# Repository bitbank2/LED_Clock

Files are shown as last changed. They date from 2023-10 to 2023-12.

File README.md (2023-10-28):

# LED_Clock
A CH32V003 low cost 'night clock'<br>
The PCB project was created with KiCad 7.0 and the firmware in the MounRiver Studio IDE. The target device is the TSSOP20 version of the CH32V003.
<br>
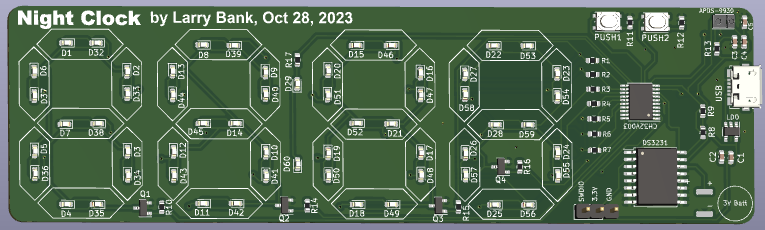
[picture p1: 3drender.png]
LED_Clock

<br>
<b>Why did you make it?</b><br>
We like to sleep in a completely black room with no LEDs visible. In the winter, the sun comes up later in the morning and it's useful to know what time it is if you wake up too early and can try to sleep a bit more. My idea was to create an LED clock which displays the time in the day and goes completely black at night. To display the time in a dark room, you wave your hand close to the clock and it will dimly display the time for a few seconds.<br>
<br>
The KiCad project files and gerbers (ready to produce at your favorite PCB fab) are in the PCB folder.<br>

If you find this project useful, please consider becoming a sponsor or sending a donation.



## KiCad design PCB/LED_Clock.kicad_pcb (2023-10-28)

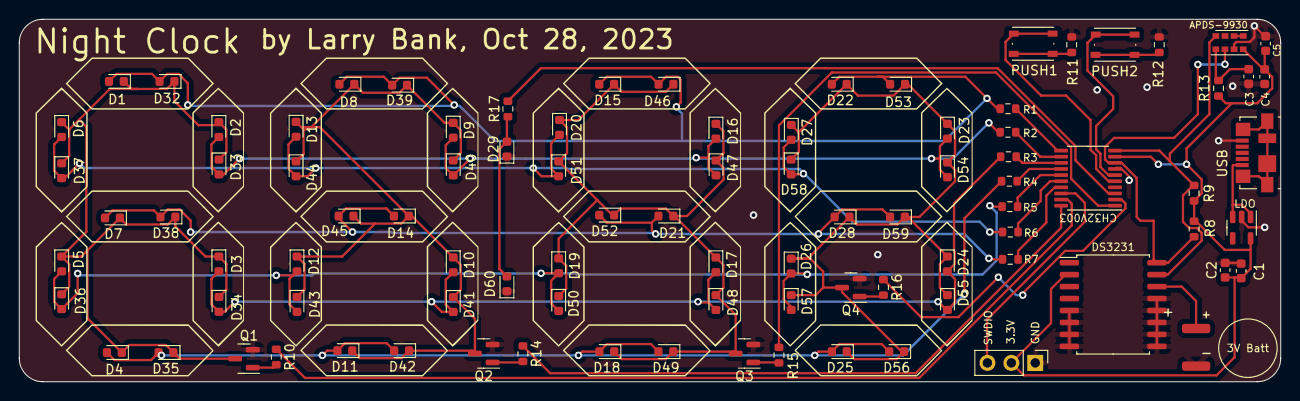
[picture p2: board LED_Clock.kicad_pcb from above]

Board: 2 copper layers, 134.0 x 38.5 mm, 93 parts (0 on the bottom side), 41 nets.

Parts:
3V Batt: Battery_Cell; CR44_Tabs
APDS-9930: APDS-9960; Avago_APDS-9960
C1, C5: 10uF; C_0603_1608Metric
C2: 100n; C_0603_1608Metric
C3, C4: 1uF; C_0603_1608Metric
CH32V003: CH32V003_TSSOP20; TSSOP-20_4.4x6.5mm_P0.65mm
D1, D2, D3, D4, D5, D6, D7, D8, D9, D10, D11, D12, D13, D14, D15, D16, D17, D18, D19, D20, D21, D22, D23, D24, D25, D26, D27, D28, D29, D32, D33, D34, D35, D36, D37, D38, D39, D40, D41, D42, D43, D44, D45, D46, D47, D48, D49, D50, D51, D52, D53, D54, D55, D56, D57, D58, D59, D60: LED; LED_0603_1608Metric
DS3231: DS3231M; SOIC-16W_7.5x10.3mm_P1.27mm
J3: PROG; PinHeader_1x03_P2.54mm_Vertical
LDO: AP2127K-3.3; SOT-23-5
PUSH1, PUSH2: SW_Push; SW_Push_1P1T_NO_Vertical_Wuerth_434133025816
Q1, Q2, Q3, Q4: AO3400A; SOT-23
R1, R2, R3, R4, R5, R6, R7, R17: 1K; R_0603_1608Metric
R8, R9: 4.7K; R_0603_1608Metric
R10, R14, R15, R16: 1k; R_0603_1608Metric
R11, R12: 10K; R_0603_1608Metric
R13: 22R; R_0603_1608Metric
USB: USB_B_Micro; USB_Micro-B_Molex_47346-0001

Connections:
+3.3V: APDS-9930.5 (LED_A), C1.1, C2.1, C4.1, C5.1, CH32V003.9 (VDD), DS3231.2 (VCC), J3.2, LDO.5 (VOUT), R8.2, R9.2, R13.2
BUTT0: CH32V003.5 (PA1/OSCI), PUSH1.2
BUTT1: CH32V003.6 (PA2/OSCO), PUSH2.2
COL1: CH32V003.19 (PD2), R10.1
COL2: CH32V003.20 (PD3), R14.1
COL3: CH32V003.1 (PD4), R15.1
COL4: CH32V003.2 (PD5), R16.1
COLON: CH32V003.3 (PD6), R17.2
GND: 3V Batt.2 (-), APDS-9930.6 (GND), C1.2, C2.2, C3.2, C4.2, C5.2, CH32V003.7 (VSS), D29.1 (K), D60.1 (K), DS3231.5 (GND), DS3231.6 (GND), DS3231.7 (GND), DS3231.8 (GND), DS3231.9 (GND), DS3231.10 (GND), DS3231.11 (GND), DS3231.12 (GND), DS3231.13 (GND), J3.1, LDO.2 (GND), Q1.2 (S), Q2.2 (S), Q3.2 (S), Q4.2 (S), R11.2, R12.2, USB.5 (GND)
unnamed: D1.2 (A), D8.2 (A), D15.2 (A), D22.2 (A), D32.2 (A), D39.2 (A), D46.2 (A), D53.2 (A), R1.1
unnamed: D1.1 (K), D2.1 (K), D3.1 (K), D4.1 (K), D5.1 (K), D6.1 (K), D7.1 (K), D32.1 (K), D33.1 (K), D34.1 (K), D35.1 (K), D36.1 (K), D37.1 (K), D38.1 (K), Q1.3 (D)
unnamed: D3.2 (A), D10.2 (A), D17.2 (A), D24.2 (A), D34.2 (A), D41.2 (A), D48.2 (A), D55.2 (A), R3.1
unnamed: D8.1 (K), D9.1 (K), D10.1 (K), D11.1 (K), D12.1 (K), D13.1 (K), D14.1 (K), D39.1 (K), D40.1 (K), D41.1 (K), D42.1 (K), D43.1 (K), D44.1 (K), D45.1 (K), Q2.3 (D)
unnamed: D4.2 (A), D11.2 (A), D18.2 (A), D25.2 (A), D35.2 (A), D42.2 (A), D49.2 (A), D56.2 (A), R4.1
unnamed: D5.2 (A), D12.2 (A), D19.2 (A), D26.2 (A), D36.2 (A), D43.2 (A), D50.2 (A), D57.2 (A), R5.1
unnamed: D6.2 (A), D13.2 (A), D20.2 (A), D27.2 (A), D37.2 (A), D44.2 (A), D51.2 (A), D58.2 (A), R6.1
unnamed: D7.2 (A), D14.2 (A), D21.2 (A), D28.2 (A), D38.2 (A), D45.2 (A), D52.2 (A), D59.2 (A), R7.1
unnamed: D15.1 (K), D16.1 (K), D17.1 (K), D18.1 (K), D19.1 (K), D20.1 (K), D21.1 (K), D46.1 (K), D47.1 (K), D48.1 (K), D49.1 (K), D50.1 (K), D51.1 (K), D52.1 (K), Q3.3 (D)
unnamed: D2.2 (A), D9.2 (A), D16.2 (A), D23.2 (A), D33.2 (A), D40.2 (A), D47.2 (A), D54.2 (A), R2.1
unnamed: D22.1 (K), D23.1 (K), D24.1 (K), D25.1 (K), D26.1 (K), D27.1 (K), D28.1 (K), D53.1 (K), D54.1 (K), D55.1 (K), D56.1 (K), D57.1 (K), D58.1 (K), D59.1 (K), Q4.3 (D)
unnamed: D29.2 (A), D60.2 (A), R17.1
unnamed: PUSH1.1, R11.1
unnamed: PUSH2.1, R12.1
unnamed: Q1.1 (G), R10.2
unnamed: Q2.1 (G), R14.2
unnamed: Q3.1 (G), R15.2
unnamed: Q4.1 (G), R16.2
unnamed: APDS-9930.3 (LDR), APDS-9930.4 (LED_K)
unnamed: APDS-9930.8 (VCC), C3.1, R13.1
ROW1: CH32V003.11 (PC1/SDA1), R1.2
ROW2: CH32V003.12 (PC2/SCL1), R2.2
ROW3: CH32V003.13 (PC3), R3.2
ROW4: CH32V003.14 (PC4), R4.2
ROW5: CH32V003.15 (PC5), R5.2
ROW6: CH32V003.16 (PC6), R6.2
ROW7: CH32V003.17 (PC7), R7.2
SCL: APDS-9930.7 (SCL), CH32V003.8 (PD0/SDA0), DS3231.16 (SCL), R8.1
SDA: APDS-9930.1 (SDA), CH32V003.10 (PC0), DS3231.15 (SDA), R9.1
SWDIO: CH32V003.18 (PD1/SCL0), J3.3
VBAT: 3V Batt.1 (+), DS3231.14 (VBAT)
VBUS: LDO.1 (VIN), LDO.3 (EN), USB.1 (VBUS)

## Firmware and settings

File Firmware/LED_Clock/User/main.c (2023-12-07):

//
// LED Clock
//
#include "debug.h"
#define CH32V003
#define BITBANG
#include "../../libraries/ch32v_hal.inl"
#include "../../libraries/rtc_eeprom.inl"
#include "../../libraries/bb_proximity.inl"

#define SDA_PIN 0xc0
#define SCL_PIN 0xd0
#define BUTT0_PIN 0xa1
#define BUTT1_PIN 0xa2
#define COLON_PIN 0xd6
struct tm myTime;
int iLux, iBrightness; // a value from 0 to 255 indicating PWM duty
#define MAX_BRIGHTNESS 256
uint8_t u8Cols[] = {0xd2, 0xd3, 0xd4, 0xd5, 0xd7};
const uint8_t u8Dig2Seg[10] = {0x3f<<1, 0x06<<1, 0x5b<<1, 0x4f<<1, 0x66<<1, 0x6d<<1, 0x7d<<1, 0x07<<1, 0x7f<<1, 0x6f<<1};

void Option_Byte_CFG(void)
{
    FLASH_Unlock();
    FLASH_EraseOptionBytes();
    FLASH_UserOptionByteConfig(OB_IWDG_SW, OB_STOP_NoRST, OB_STDBY_NoRST, OB_RST_NoEN);
    FLASH_Lock();
}

void ShowDigit(uint8_t u8Digit, uint8_t u8Column, int iBright, int iDelay)
{
	int iOn, iOff;
	uint8_t u8;

	if (iBright <= 0) {
		Delay_Us(iDelay);
		return;
	}
	iOn = (iDelay * iBright) >> 8;
	iOff = (iDelay - iOn);
	if (u8Column == 4) { // colon
		if (u8Digit) {
			digitalWrite(COLON_PIN, 1);
			Delay_Us(iOn);
			digitalWrite(COLON_PIN, 0);
			Delay_Us(iOff);
		} else {
			Delay_Us(iOn+iOff); // keep time consistent
		}
	} else {
		u8 = u8Dig2Seg[u8Digit];
		digitalWrite8(0xc0, u8);
		digitalWrite(u8Cols[u8Column], 1);
		Delay_Us(iOn);
		digitalWrite(u8Cols[u8Column], 0);
		Delay_Us(iOff);
	}
} /* ShowDigit() */

void AddMinutes(int iMin)
{
	myTime.tm_min += iMin;
	if (myTime.tm_min >= 60) {
		myTime.tm_min -= 60;
		myTime.tm_hour++;
		if (myTime.tm_hour > 23)
			myTime.tm_hour = 0;
	}
	rtcSetTime(&myTime);
} /* AddMinutes()*/

int GetDistance(void)
{
    int i, iLux, iDist;
    const uint8_t iDistLow[26] = {200,200,200,200,200,200,200,200,
                               200,200,150,140,130,120,110,105,
                               100,94,90,86,82,78,74,73,72,71};
    const uint8_t iDistHigh[26] = {  70, 68, 65, 60, 58, 55, 50, 48,
                                44, 42, 40, 38, 37, 36, 35, 34,
                                33, 32, 31, 30, 30, 30, 30, 30, 30, 30};
    i = bbp_getProximity();
    if (i < 192) iDist = iDistLow[i >> 3];
    else iDist = iDistHigh[(i >> 5)-6];
    return iDist;
} /* GetDistance() */

void UpdateBrightness(int iTicks)
{
    iLux = bbp_getLight();
    if (iLux <= 20 && iBrightness != 0 && iTicks == 0) { // room went dark
    	iBrightness = 0; // go dark
    } else if (iLux > 20 && iBrightness == 0) { // room went light
		iBrightness = 50+iLux;
		if (iBrightness > MAX_BRIGHTNESS) {
			iBrightness = MAX_BRIGHTNESS; // max brightness
		}
    }
} /* UpdateBrightness() */

int main(void)
{
int i, j, iTicks = 0;
int iDistance;
int iColor;

    NVIC_PriorityGroupConfig(NVIC_PriorityGroup_2);
    Delay_Init();
//    Option_Byte_CFG(); // allow PD7 to be used as GPIO
    rtcInit(RTC_DS3231, SDA_PIN, SCL_PIN);
    pinMode(BUTT0_PIN, INPUT_PULLUP);
    pinMode(BUTT1_PIN, INPUT_PULLUP);
    pinMode(COLON_PIN, OUTPUT);
    bbp_init();
    bbp_start(BBP_CAPS_ALS | BBP_CAPS_PROXIMITY);
    bbp_setLEDBoost(3);

    for (i=0; i<5; i++) {
    	pinMode(u8Cols[i], OUTPUT);
    	digitalWrite(u8Cols[i], 0);
    }
    for (i=0xc1; i<=0xc7; i++) { // enable all rows as outputs
    	pinMode(i, OUTPUT);
    	digitalWrite(i, 0);
    }
    rtcGetTime(&myTime);
    UpdateBrightness(0); // start from reset with the appropriate brightness
    while(1)
    {
 //   	i = bbp_getLight();
//    	i = bbp_getProximity();
        for (j=0; j<200; j++) {
#ifdef BOGUS
        	ShowDigit(i/1000, 0, iBrightness,1000);
        	ShowDigit((i % 1000)/100, 1, iBrightness, 1000);
        	ShowDigit((i % 100)/10, 2, iBrightness,1000);
        	ShowDigit(i % 10, 3, iBrightness, 1000);
#else
        	if (myTime.tm_hour > 9) {
        		i = myTime.tm_hour / 10;
   				ShowDigit(i, 0, iBrightness, 1000);
        	} else {
        		Delay_Us(1000);
        	}
        	i = myTime.tm_hour % 10;
   			ShowDigit(i, 1, iBrightness, 1000);
        	i = myTime.tm_min / 10;
   			ShowDigit(i, 2, iBrightness, 1000);
        	i = myTime.tm_min % 10;
   			ShowDigit(i, 3, iBrightness, 1000);
   			ShowDigit(myTime.tm_sec & 1, 4, iBrightness, 1000); // blinking colon
   			if ((j == 0 || j == 100) && digitalRead(BUTT1_PIN) == 0) { // fast change
   				AddMinutes(10);
   			}
#endif
        } // for j
		if (digitalRead(BUTT0_PIN) == 0) { // slow change
			AddMinutes(1);
		}

#ifndef FUTURE
		if ((myTime.tm_sec & 7) == 7) { // check light level every 8 seconds
			UpdateBrightness(iTicks);
		}
#endif
		if ((myTime.tm_sec & 15) == 15) {
	        rtcGetTime(&myTime); // keep the time accurate
		} else { // manually increment the time to prevent flicker on the LEDs
			myTime.tm_sec++;
			if (myTime.tm_sec >= 60) {
				myTime.tm_sec -= 60;
				myTime.tm_min++;
				if (myTime.tm_min >= 60) {
					myTime.tm_min -= 60;
					myTime.tm_hour++;
				}
			}
		}
#ifndef FUTURE
		if (iLux < 20) { // dark room
//			iDistance = GetDistance();
//			i = 160 - iDistance; // hand nearby?
		    i = bbp_getProximity();
			if (i > 2100)  { // hand nearby
				iTicks = 5;
				iBrightness = 20;
			} else if (iTicks > 0) {
				iTicks--;
				if (iTicks == 0) iBrightness = 0; // go black again after 5 seconds
			} else {
				Delay_Ms(250); // waiting for more samples
			}
		}
#endif
    }
} /* main() */
